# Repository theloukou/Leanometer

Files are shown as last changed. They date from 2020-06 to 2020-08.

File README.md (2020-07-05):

# Leanometer
Arduino-based motorcycle leanometer

This is version 1 of my open-source motorcycle leanometer, based on *Arduino*.
Designed mainly to be compact, low cost, and easy to assemble with household equipment/average soldering skills.

3D printed enclosure has been tested to be water resistant over 12 hour water exposure. Additional weather proofing can be achieved by using some kind of conformal coating on electronics (i.e. Kontakt Plastik 70).

Additional parts needed are:
1.  **GY-521 MPU-6050** IMU module
2. 26.5mm x 29mm x 3mm Plexiglass piece
3. 6 pieces of M2.5x5mm bolts
4. some kind of 2 component adhesive/thermoglue

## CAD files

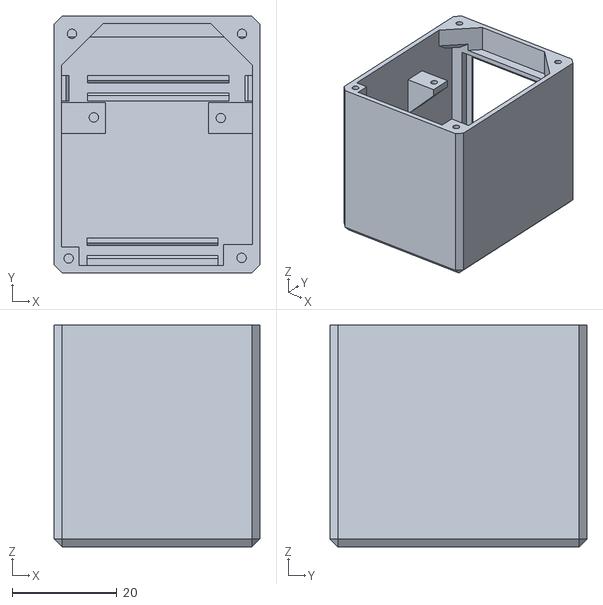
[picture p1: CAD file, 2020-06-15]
3D/main_body.stl
39.3 x 49.1 x 42.4

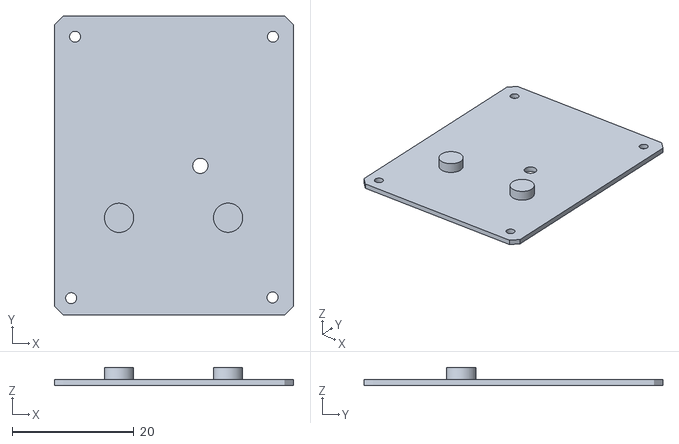
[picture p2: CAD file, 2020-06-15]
3D/flex_lid.stl
39.3 x 49.1 x 3.00

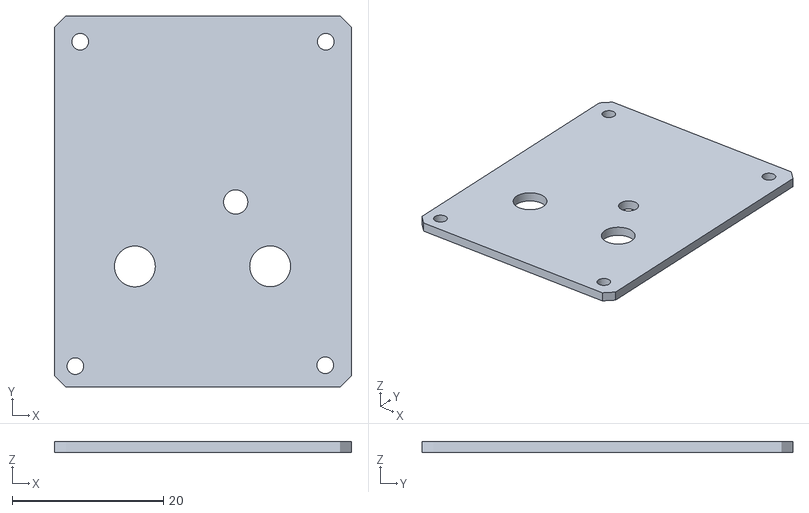
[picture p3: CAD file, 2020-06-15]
3D/bot_lid.stl
39.3 x 49.1 x 1.50

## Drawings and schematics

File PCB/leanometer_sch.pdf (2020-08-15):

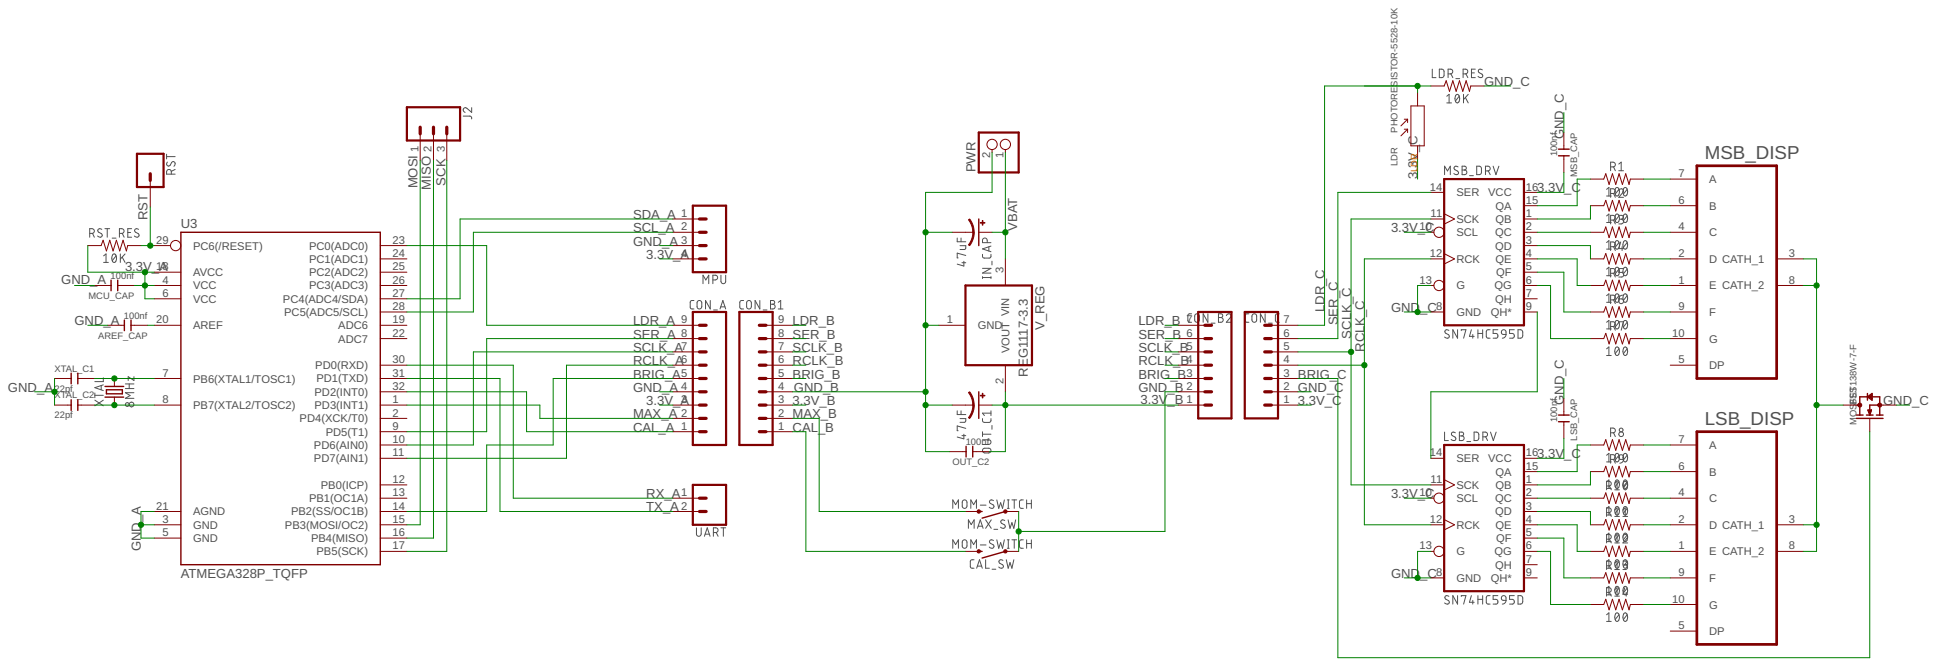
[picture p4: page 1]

BSS138W-7-F ATMEGA328P_TQFP 100nf 100nf 100nf 22pf 22pf REG1117-3.3 100nf 100nf PHOTORESISTOR-5528-10K C 4 B 6 A 7 D 2 E 1 CATH_1 3 CATH_2 8 F 9 G 10 DP 5 MSB_DISP C 4 B 6 A 7 D 2 E 1 CATH_1 3 CATH_2 8 F 9 G 10 DP 5 LSB_DISP QB 1 QC 2 QD 3 QE 4 QF 5 QG 6 QH 7 SCL 10 SCK 11 RCK 12 G 13 SER 14 QA 15 QH* 9 GND 8 VCC 16 QB 1 QC 2 QD 3 QE 4 QF 5 QG 6 QH 7 SCL 10 SCK 11 RCK 12 G 13 SER 14 QA 15 QH* 9 GND 8 VCC 16 MOSFET PB5(SCK) 17 PB7(XTAL2/TOSC2) 8 PB6(XTAL1/TOSC1) 7 GND 3 GND 5 VCC 4 VCC 6 AGND 21 AREF 20 AVCC 18 PB4(MISO) 16 PB3(MOSI/OC2) 15 PB2(SS/OC1B) 14 PB1(OC1A) 13 PB0(ICP) 12 PD7(AIN1) 11 PD6(AIN0) 10 PD5(T1) 9 PD4(XCK/T0) 2 PD3(INT1) 1 PD2(INT0) 32 PD1(TXD) 31 PD0(RXD) 30 ADC7 22 ADC6 19 PC5(ADC5/SCL) 28 PC4(ADC4/SDA) 27 PC3(ADC3) 26 PC2(ADC2) 25 PC1(ADC1) 24 PC0(ADC0) 23 PC6(/RESET) 29 U3 MSB_CAP LSB_CAP MCU_CAP XTAL_C1 XTAL_C2 1234 VIN 3 VOUT 2 GND 1 V_REG OUT_C2 AREF_CAP 12 LDR 1234567 1234567 123456789 123456789 21 PW123R RST SCLK_C RCLK_C VBAT MOSI MISO SCK BRIG_C LDR_C SER_C 3.3V_C 3.3V_C 3.3V_C 3.3V_C 3.3V_C 3.3V_C GND_C GND_C GND_C GND_C GND_C GND_C GND_C GND_B GND_B 3.3V_B 3.3V_B CAL_B MAX_B BRIG_B BRIG_B RCLK_B RCLK_B SCLK_B SCLK_B SER_B SER_B LDR_A LDR_B LDR_B SER_A SCLK_A RCLK_A BRIG_A GND_A GND_A GND_A GND_A GND_A GND_A 3.3V_A 3.3V_A 3.3V_A MAX_A CAL_A SDA_A SCL_A RX_A TX_A LDR

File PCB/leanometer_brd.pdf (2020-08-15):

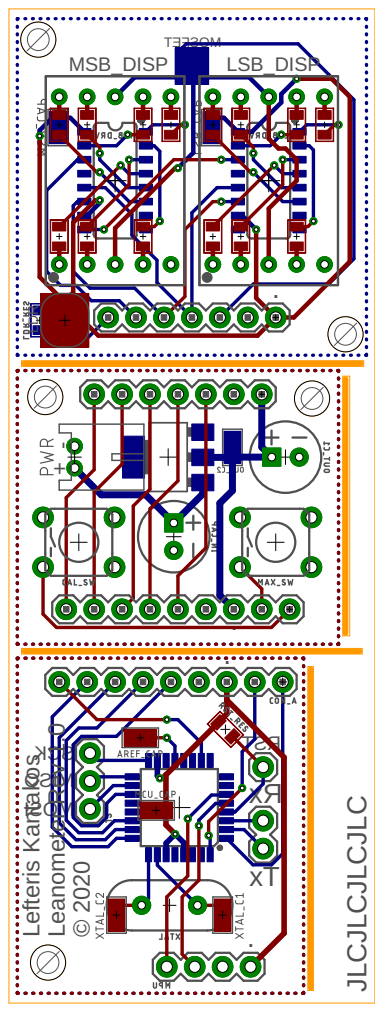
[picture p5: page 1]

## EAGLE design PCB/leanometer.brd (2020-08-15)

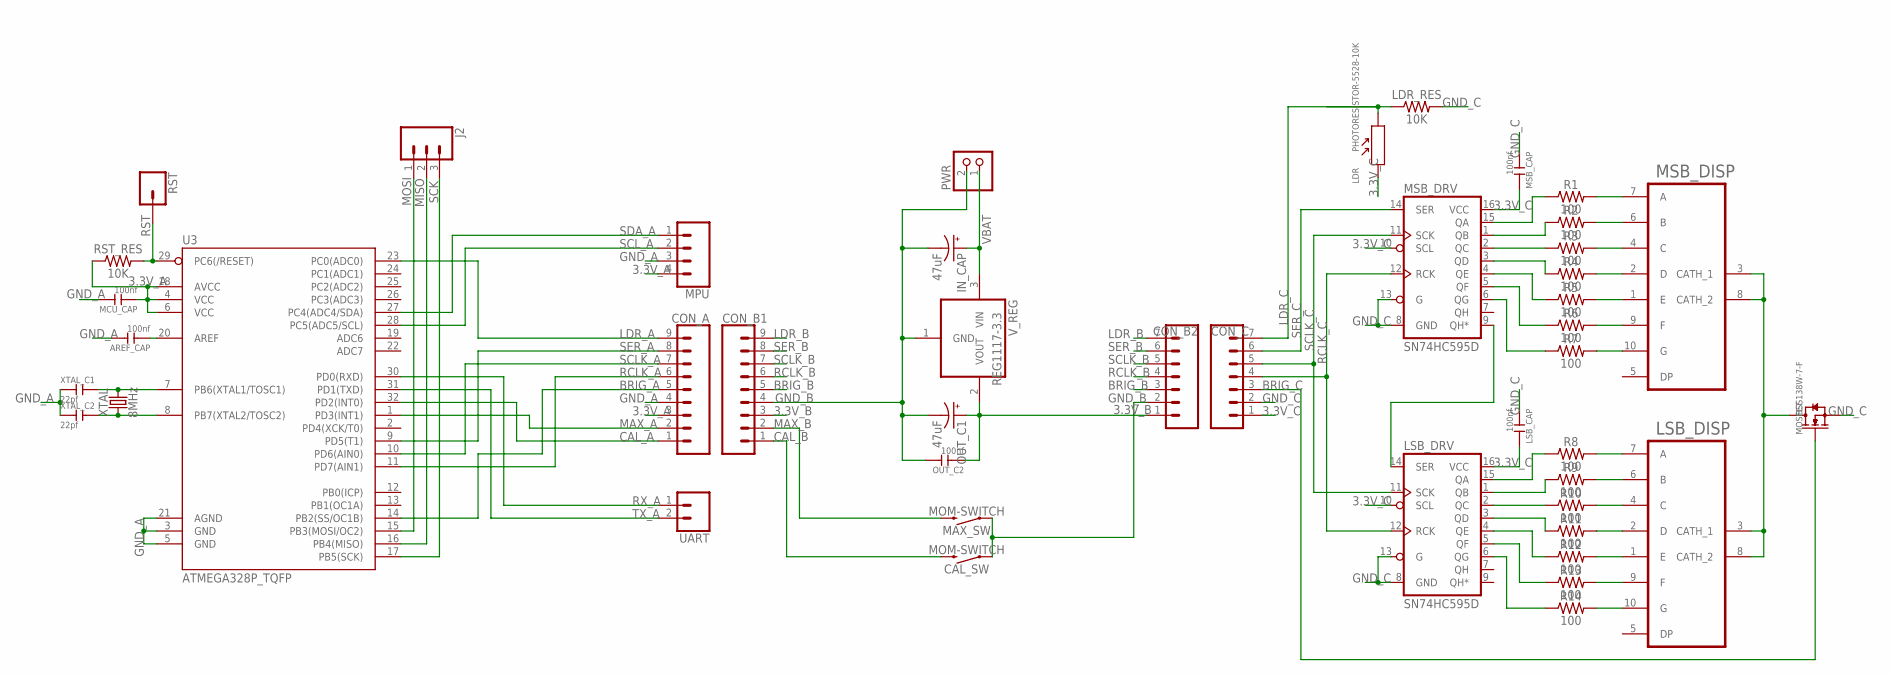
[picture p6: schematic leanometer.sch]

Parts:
AREF_CAP: 100nf; C0805
CAL_SW: MOM-SWITCH; TACTILE_SWITCH_PTH_6.0MM
CON_A: CONN_09; 1X09
CON_B1: CONN_09; 1X09
CON_B2: CONN_07; 1X07
CON_C: CONN_07; 1X07
IN_CAP: 47uF; CPOL-RADIAL-2.5MM-6.5MM
J2: CONN_03; 1X03
LDR: PHOTORESISTOR-5528-10K; SNR2-3.0
LDR_RES: 10K; 0805
LSB_CAP: 100nf; C0805
LSB_DISP: OPD-S5621LE-BW; 0.56''_LED_DISPLAY
LSB_DRV: SN74HC595D; SO16
MAX_SW: MOM-SWITCH; TACTILE_SWITCH_PTH_6.0MM
MCU_CAP: 100nf; C0805
MOSFET: BSS138W-7-F; SOT-23
MPU: CONN_04; 1X04
MSB_CAP: 100nf; C0805
MSB_DISP: OPD-S5621LE-BW; 0.56''_LED_DISPLAY
MSB_DRV: SN74HC595D; SO16
OUT_C1: 47uF; CPOL-RADIAL-2.5MM-6.5MM
OUT_C2: 100nf; C0805
PWR: JST_2PIN-THM-RA; JST-PH-2-THM-RA
R1, R2, R3, R4, R5, R6, R7, R8, R9, R10, R11, R12, R13, R14: 100; 0805
RST: CONN_01; 1X01
RST_RES: 10K; 0805
U3: ATMEGA328P_TQFP; TQFP32-08
UART: CONN_02; 1X02
V_REG: REG1117-3.3; SOT223
XTAL: 8MHz; HC49US
XTAL_C1, XTAL_C2: 22pf; C0805

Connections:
3.3V_A: CON_A.3, MCU_CAP.1, MPU.4, RST_RES.1, U3.4 (VCC), U3.6 (VCC), U3.18 (AVCC)
3.3V_B: CON_B1.3, CON_B2.1, OUT_C1.1 (+), OUT_C2.1, V_REG.2 (VOUT)
3.3V_C: CON_C.1, LDR.1, LSB_CAP.2, LSB_DRV.10 (SCL), LSB_DRV.16 (VCC), MSB_CAP.2, MSB_DRV.10 (SCL), MSB_DRV.16 (VCC)
BRIG_A: CON_A.5, U3.14 (PB2(SS/OC1B))
BRIG_B: CON_B1.5, CON_B2.3
BRIG_C: CON_C.3, MOSFET.1 (G)
CAL_A: CON_A.1, U3.32 (PD2(INT0))
CAL_B: CAL_SW.3 (2), CON_B1.1
GND_A: AREF_CAP.2, CON_A.4, MCU_CAP.2, MPU.3, U3.3 (GND), U3.5 (GND), U3.21 (AGND), XTAL_C1.1, XTAL_C2.1
GND_B: CAL_SW.1, CON_B1.4, CON_B2.2, IN_CAP.2 (-), MAX_SW.1, OUT_C1.2 (-), OUT_C2.2, PWR.2 (1), V_REG.1 (GND)
GND_C: CON_C.2, LDR_RES.2, LSB_CAP.1, LSB_DRV.8 (GND), LSB_DRV.13 (G), MOSFET.2 (S), MSB_CAP.1, MSB_DRV.8 (GND), MSB_DRV.13 (G)
LDR_A: CON_A.9, U3.23 (PC0(ADC0))
LDR_B: CON_B1.9, CON_B2.7
LDR_C: CON_C.7, LDR.2, LDR_RES.1
MAX_A: CON_A.2, U3.1 (PD3(INT1))
MAX_B: CON_B1.2, MAX_SW.3 (2)
MISO: J2.2, U3.16 (PB4(MISO))
MOSI: J2.1, U3.15 (PB3(MOSI/OC2))
unnamed: MSB_DISP.7 (A), R1.2
unnamed: MSB_DISP.6 (B), R2.2
unnamed: MSB_DISP.4 (C), R3.2
unnamed: MSB_DISP.2 (D), R4.2
unnamed: MSB_DISP.1 (E), R5.2
unnamed: MSB_DISP.9 (F), R6.2
unnamed: MSB_DISP.10 (G), R7.2
unnamed: LSB_DISP.7 (A), R8.2
unnamed: LSB_DISP.6 (B), R9.2
unnamed: LSB_DISP.4 (C), R10.2
unnamed: LSB_DISP.2 (D), R11.2
unnamed: LSB_DISP.1 (E), R12.2
unnamed: LSB_DISP.9 (F), R13.2
unnamed: LSB_DISP.10 (G), R14.2
unnamed: MSB_DRV.1 (QB), R2.1
unnamed: LSB_DRV.1 (QB), R9.1
unnamed: MSB_DRV.2 (QC), R3.1
unnamed: MSB_DRV.3 (QD), R4.1
unnamed: MSB_DRV.4 (QE), R5.1
unnamed: MSB_DRV.5 (QF), R6.1
unnamed: MSB_DRV.6 (QG), R7.1
unnamed: MSB_DRV.15 (QA), R1.1
unnamed: LSB_DRV.15 (QA), R8.1
unnamed: LSB_DRV.2 (QC), R10.1
unnamed: LSB_DRV.3 (QD), R11.1
unnamed: LSB_DRV.4 (QE), R12.1
unnamed: LSB_DRV.5 (QF), R13.1
unnamed: LSB_DRV.6 (QG), R14.1
unnamed: LSB_DRV.14 (SER), MSB_DRV.9 (QH*)
unnamed: LSB_DISP.3 (CATH_1), LSB_DISP.8 (CATH_2), MOSFET.3 (D), MSB_DISP.3 (CATH_1), MSB_DISP.8 (CATH_2)
unnamed: U3.7 (PB6(XTAL1/TOSC1)), XTAL.2, XTAL_C1.2
unnamed: U3.8 (PB7(XTAL2/TOSC2)), XTAL.1, XTAL_C2.2
unnamed: AREF_CAP.1, U3.20 (AREF)
RCLK_A: CON_A.6, U3.11 (PD7(AIN1))
RCLK_B: CON_B1.6, CON_B2.4
RCLK_C: CON_C.4, LSB_DRV.12 (RCK), MSB_DRV.12 (RCK)
RST: RST.1, RST_RES.2, U3.29 (PC6(/RESET))
RX_A: U3.30 (PD0(RXD)), UART.1
SCK: J2.3, U3.17 (PB5(SCK))
SCLK_A: CON_A.7, U3.10 (PD6(AIN0))
SCLK_B: CON_B1.7, CON_B2.5
SCLK_C: CON_C.5, LSB_DRV.11 (SCK), MSB_DRV.11 (SCK)
SCL_A: MPU.2, U3.28 (PC5(ADC5/SCL))
SDA_A: MPU.1, U3.27 (PC4(ADC4/SDA))
SER_A: CON_A.8, U3.9 (PD5(T1))
SER_B: CON_B1.8, CON_B2.6
SER_C: CON_C.6, MSB_DRV.14 (SER)
TX_A: U3.31 (PD1(TXD)), UART.2
VBAT: IN_CAP.1 (+), PWR.1 (2), V_REG.3 (VIN)

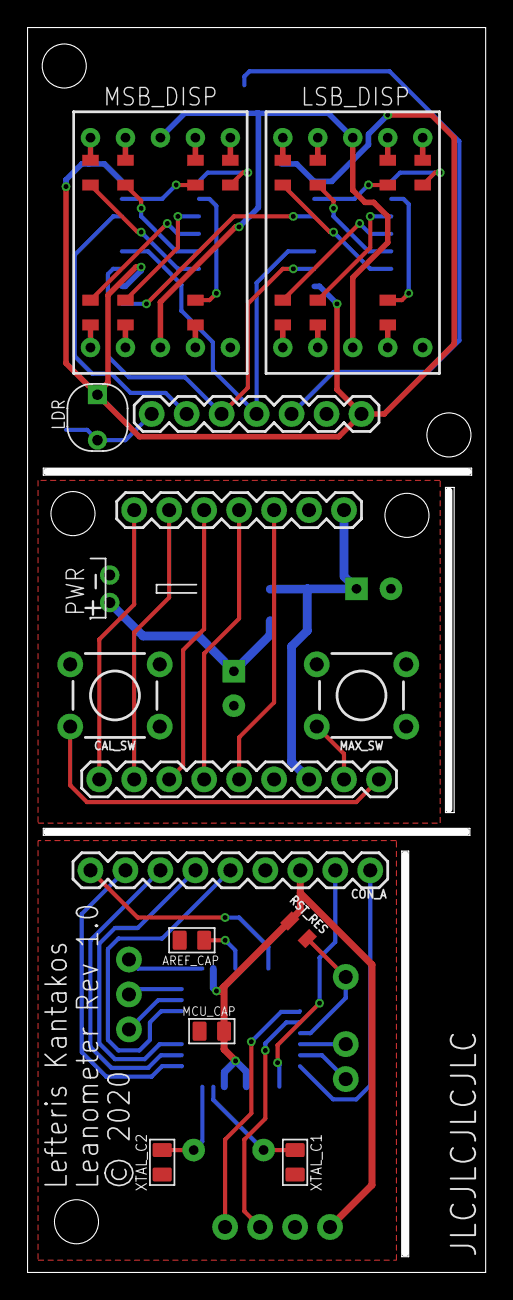
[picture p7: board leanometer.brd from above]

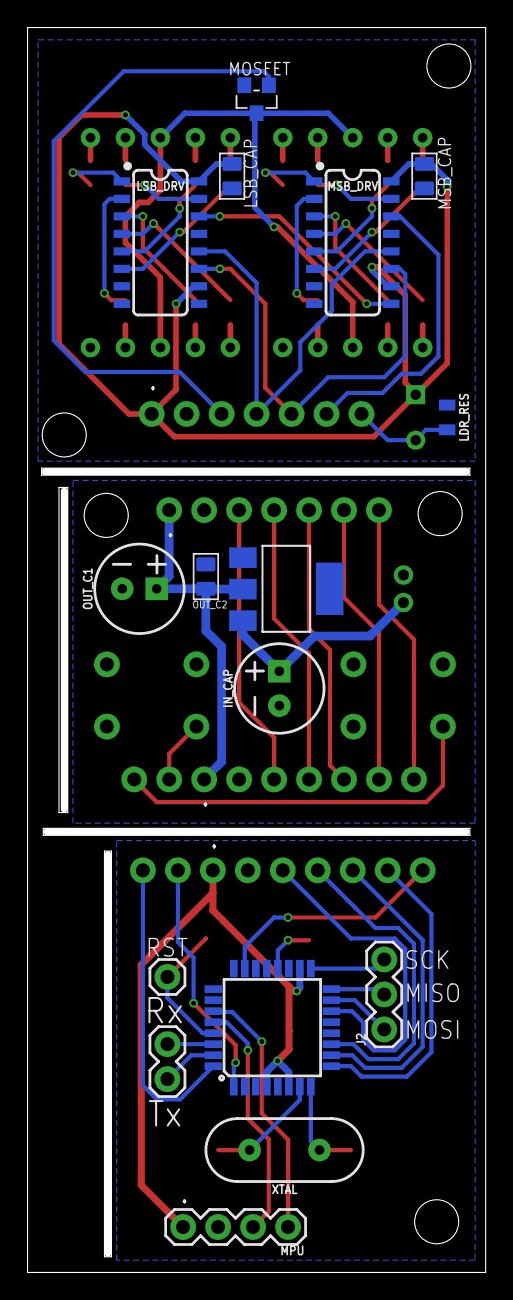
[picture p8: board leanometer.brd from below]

Board: 2 copper layers, 33.3 x 90.4 mm, 45 parts (16 on the bottom side), 67 nets.

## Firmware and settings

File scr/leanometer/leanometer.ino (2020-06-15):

#define CAL_BUTTON 2
#define MAX_BUTTON 3
#define BRIGHTNESS_PIN 10
#define LDR A0
#define LDR_MIN_THRES 200
#define LDR_MAX_THRES 800
//#define CA_7SDU
#define CC_7SDU

#include "ShiftRegister74HC595.h"
#include "I2Cdev.h"
#include "EEPROM.h"
#include "MPU6050_6Axis_MotionApps_V6_12.h"
#if I2CDEV_IMPLEMENTATION == I2CDEV_ARDUINO_WIRE
#include "Wire.h"
#endif

ShiftRegister74HC595<2> disp(5, 6, 7);
MPU6050 IMU;

// MPU control/status vars
bool IMUReady = false;  // set true if DMP init was successful
uint8_t IMUdevStatus;      // return status after each device operation (0 = success, !0 = error)
uint16_t IMUpacketSize;    // expected DMP packet size (default is 42 bytes)
uint16_t IMUfifoCount;     // count of all bytes currently in FIFO
uint8_t IMUfifoBuffer[64]; // FIFO storage buffer

// orientation/motion vars
Quaternion IMUq;               // [w, x, y, z] quaternion container
VectorFloat IMUgravity;        // [x, y, z]  gravity vector
float IMUypr[3] = {0, 0, 0};   // [yaw, pitch, roll] yaw/pitch/roll container and gravity vector

int xAccelOffset, yAccelOffset, zAccelOffset, xGyroOffset, yGyroOffset, zGyroOffset;
String serialStr;
double angle, maxAngle = 0;
bool calTriggered = false, maxTriggered = false;
unsigned long buttonTime;

void setup() {
#ifdef CA_7SDU
  disp.setAllHigh();
#endif

#ifdef CC_7SDU
  disp.setAllLow();
#endif

TCCR1B = TCCR1B & B11111000 | B00000001;  //pin 9+10 pwm freq 31.372 KHz
//TCCR1B = TCCR1B & B11111000 | B00000100;  //pin 9+10 pwm freq 122.55 Hz
//TCCR1B = TCCR1B & B11111000 | B00000101;  //pin 9+10 pwm freq 30.64 Hz

  serialStr.reserve(40);
  Serial.begin(115200);

  pinMode(CAL_BUTTON, INPUT_PULLUP);
  pinMode(MAX_BUTTON, INPUT_PULLUP);
  pinMode(BRIGHTNESS_PIN, OUTPUT);
  attachInterrupt(digitalPinToInterrupt(CAL_BUTTON), calButton, FALLING);
  attachInterrupt(digitalPinToInterrupt(MAX_BUTTON), maxButton, FALLING);

  eeprom_get();

  // join I2C bus (I2Cdev library doesn't do this automatically)
  Wire.begin();
  Wire.setClock(400000); // 400kHz I2C clock

  //initialise IMU
  IMUsetup();

  Serial.println("Ready!");

  analogWrite(BRIGHTNESS_PIN, 25);

  //reset IMU FIFOs for clean start
  IMU.resetFIFO();
}

void loop() {
  // if IMU programming failed, don't try to do anything
  if (!IMUReady) return;  //halt if MPU is missing

  IMUdata();
//  Serial.println(angle);
  updateDisp(abs(angle));

  if (abs(angle) > maxAngle) {
    maxAngle = abs(angle);
  }

  brightness();

  calCheck();
  maxCheck();
}

void calButton() {
  calTriggered = true;
}

void maxButton() {
  maxTriggered = true;
}

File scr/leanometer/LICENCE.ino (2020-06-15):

/* ============================================
  Leanometer project code is placed under the MIT license
  Copyright (c) 2020 Lefteris Kantakos
  Permission is hereby granted, free of charge, to any person obtaining a copy
  of this software and associated documentation files (the "Software"), to deal
  in the Software without restriction, including without limitation the rights
  to use, copy, modify, merge, publish, distribute, sublicense, and/or sell
  copies of the Software, and to permit persons to whom the Software is
  furnished to do so, subject to the following conditions:
  The above copyright notice and this permission notice shall be included in
  all copies or substantial portions of the Software.
  THE SOFTWARE IS PROVIDED "AS IS", WITHOUT WARRANTY OF ANY KIND, EXPRESS OR
  IMPLIED, INCLUDING BUT NOT LIMITED TO THE WARRANTIES OF MERCHANTABILITY,
  FITNESS FOR A PARTICULAR PURPOSE AND NONINFRINGEMENT. IN NO EVENT SHALL THE
  AUTHORS OR COPYRIGHT HOLDERS BE LIABLE FOR ANY CLAIM, DAMAGES OR OTHER
  LIABILITY, WHETHER IN AN ACTION OF CONTRACT, TORT OR OTHERWISE, ARISING FROM,
  OUT OF OR IN CONNECTION WITH THE SOFTWARE OR THE USE OR OTHER DEALINGS IN
  THE SOFTWARE.
  ===============================================
*/

/* ============================================
  I2Cdev device library code is placed under the MIT license
  Copyright (c) 2012 Jeff Rowberg
  Permission is hereby granted, free of charge, to any person obtaining a copy
  of this software and associated documentation files (the "Software"), to deal
  in the Software without restriction, including without limitation the rights
  to use, copy, modify, merge, publish, distribute, sublicense, and/or sell
  copies of the Software, and to permit persons to whom the Software is
  furnished to do so, subject to the following conditions:
  The above copyright notice and this permission notice shall be included in
  all copies or substantial portions of the Software.
  THE SOFTWARE IS PROVIDED "AS IS", WITHOUT WARRANTY OF ANY KIND, EXPRESS OR
  IMPLIED, INCLUDING BUT NOT LIMITED TO THE WARRANTIES OF MERCHANTABILITY,
  FITNESS FOR A PARTICULAR PURPOSE AND NONINFRINGEMENT. IN NO EVENT SHALL THE
  AUTHORS OR COPYRIGHT HOLDERS BE LIABLE FOR ANY CLAIM, DAMAGES OR OTHER
  LIABILITY, WHETHER IN AN ACTION OF CONTRACT, TORT OR OTHERWISE, ARISING FROM,
  OUT OF OR IN CONNECTION WITH THE SOFTWARE OR THE USE OR OTHER DEALINGS IN
  THE SOFTWARE.
  ===============================================
*/

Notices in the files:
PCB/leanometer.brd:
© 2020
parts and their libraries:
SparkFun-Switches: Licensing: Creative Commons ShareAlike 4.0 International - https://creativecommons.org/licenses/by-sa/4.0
